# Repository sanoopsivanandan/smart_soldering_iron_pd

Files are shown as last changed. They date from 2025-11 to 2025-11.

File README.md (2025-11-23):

# Smart Soldering Iron (USB-C PD Powered)

A compact and affordable **USB-C PD powered smart soldering iron** designed for hobbyists and experimenters.
The project uses a **C210-style tip**, an **ATmega328P-AU**, and includes an **OLED display** and **accelerometer** for smart functions.

This repository currently contains **hardware-only KiCad files**. Firmware development will begin later.

---

## 📏 PCB Specifications

* **Size:** 15 mm × 107 mm
* **Layers:** 2-layer PCB
* **Form factor:** Ultra-slim to fit inside a pen-style soldering iron handle
* **Designed for:** C210-style soldering tip

---

## 🔌 Power System

* **Input:** USB-C Power Delivery
* **Supported Voltage:** Up to **12V** (currently limited to 12V for testing)
* **Purpose:** Drive the heater inside the C210 tip and power the MCU + peripherals

---

## 🧠 Microcontroller

* **MCU:** ATmega328P-AU
* **Package:** TQFP-32 (same package used in Arduino Uno SMD version)
* **Reason:** Easy programming, hobbyist-friendly, widely supported by Arduino IDE

---

## 🔥 Soldering Tip Support

* **Tip Type:** C210 series
* **Temperature Sensor:** Built-in thermocouple inside the tip
* **Connection:** Compact, high-current heater + thermocouple feedback

---

## 📟 Display & User Interface

* **Display:** 128×32 OLED
* **Navigation:** Buttons + planned touch navigation for PDF schematic viewing
* **Future UI Features:**

  * Temperature selection menu
  * Left-hand / right-hand screen rotation
  * Real-time tip temperature graph (optional)

---

## 🧭 Motion / Sleep Features

* **Accelerometer:** LIS3DHTR
* Planned features:

  * Auto-sleep when inactive
  * Wake-on-shake
  * Handle movement detection for safety

---

## 🧪 Project Status

| Category | Status |
| --- | --- |
| Hardware | ✔ Completed (prototype ready) |
| Schematics | ✔ Completed |
| PCB Layout | ✔ Completed |
| Firmware | ❌ Not started |
| Testing | ❌ Pending |

---

## 🧰 Development Plans (Firmware)

Firmware will be written primarily using **Arduino IDE**, with possible low-level C enhancements.

Planned firmware features:

* PID temperature control
* USB-C PD negotiation and power step handling
* On-screen temperature display
* Menu navigation
* Accelerometer-based sleep mode
* Tip calibration

---

## 📂 Repository Structure

* `.kicad_pro` – Main KiCad project file
* `.kicad_sch` – Schematic files
* `.kicad_pcb` – PCB layout
* `pcb_front.pdf` / `pcb_back.pdf` – PDF views of the PCB
* Additional supporting schematic sheets

Touch navigation support will be added to PDF schematics to improve readability during review.

---

## 🎯 Project Goal

To create an **affordable**, **compact**, and **easily buildable** smart soldering iron that:

* Hobbyists can assemble with basic tools
* Works reliably with USB-C PD chargers
* Uses a high-quality C210 tip
* Provides a solid foundation for firmware experimentation

---

## 📜 License

No license added yet — you may add MIT / GPL / CERN OHL based on your preference.

---

## 🤝 Contributions

Contributions and suggestions are welcome once firmware development begins!

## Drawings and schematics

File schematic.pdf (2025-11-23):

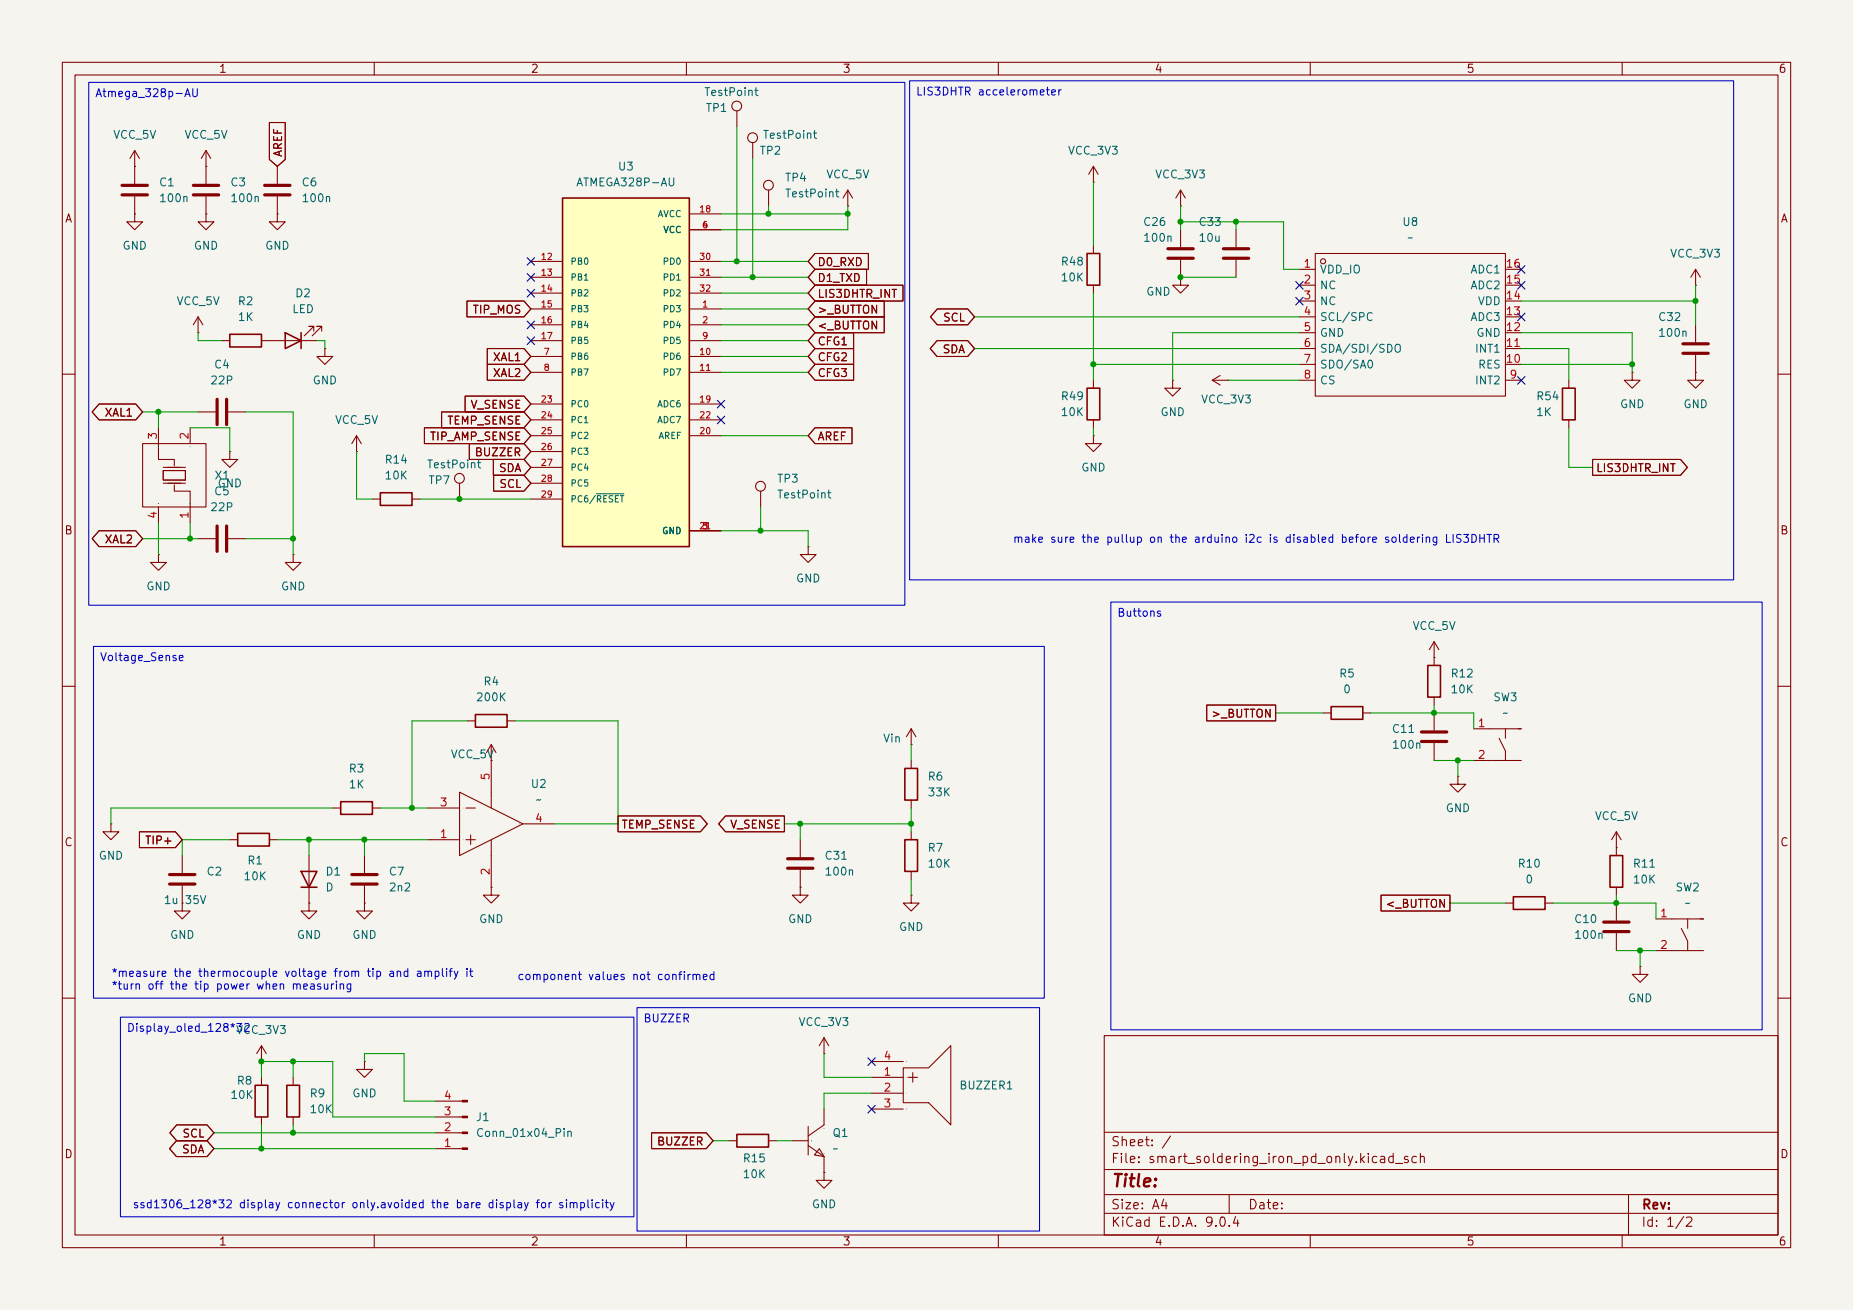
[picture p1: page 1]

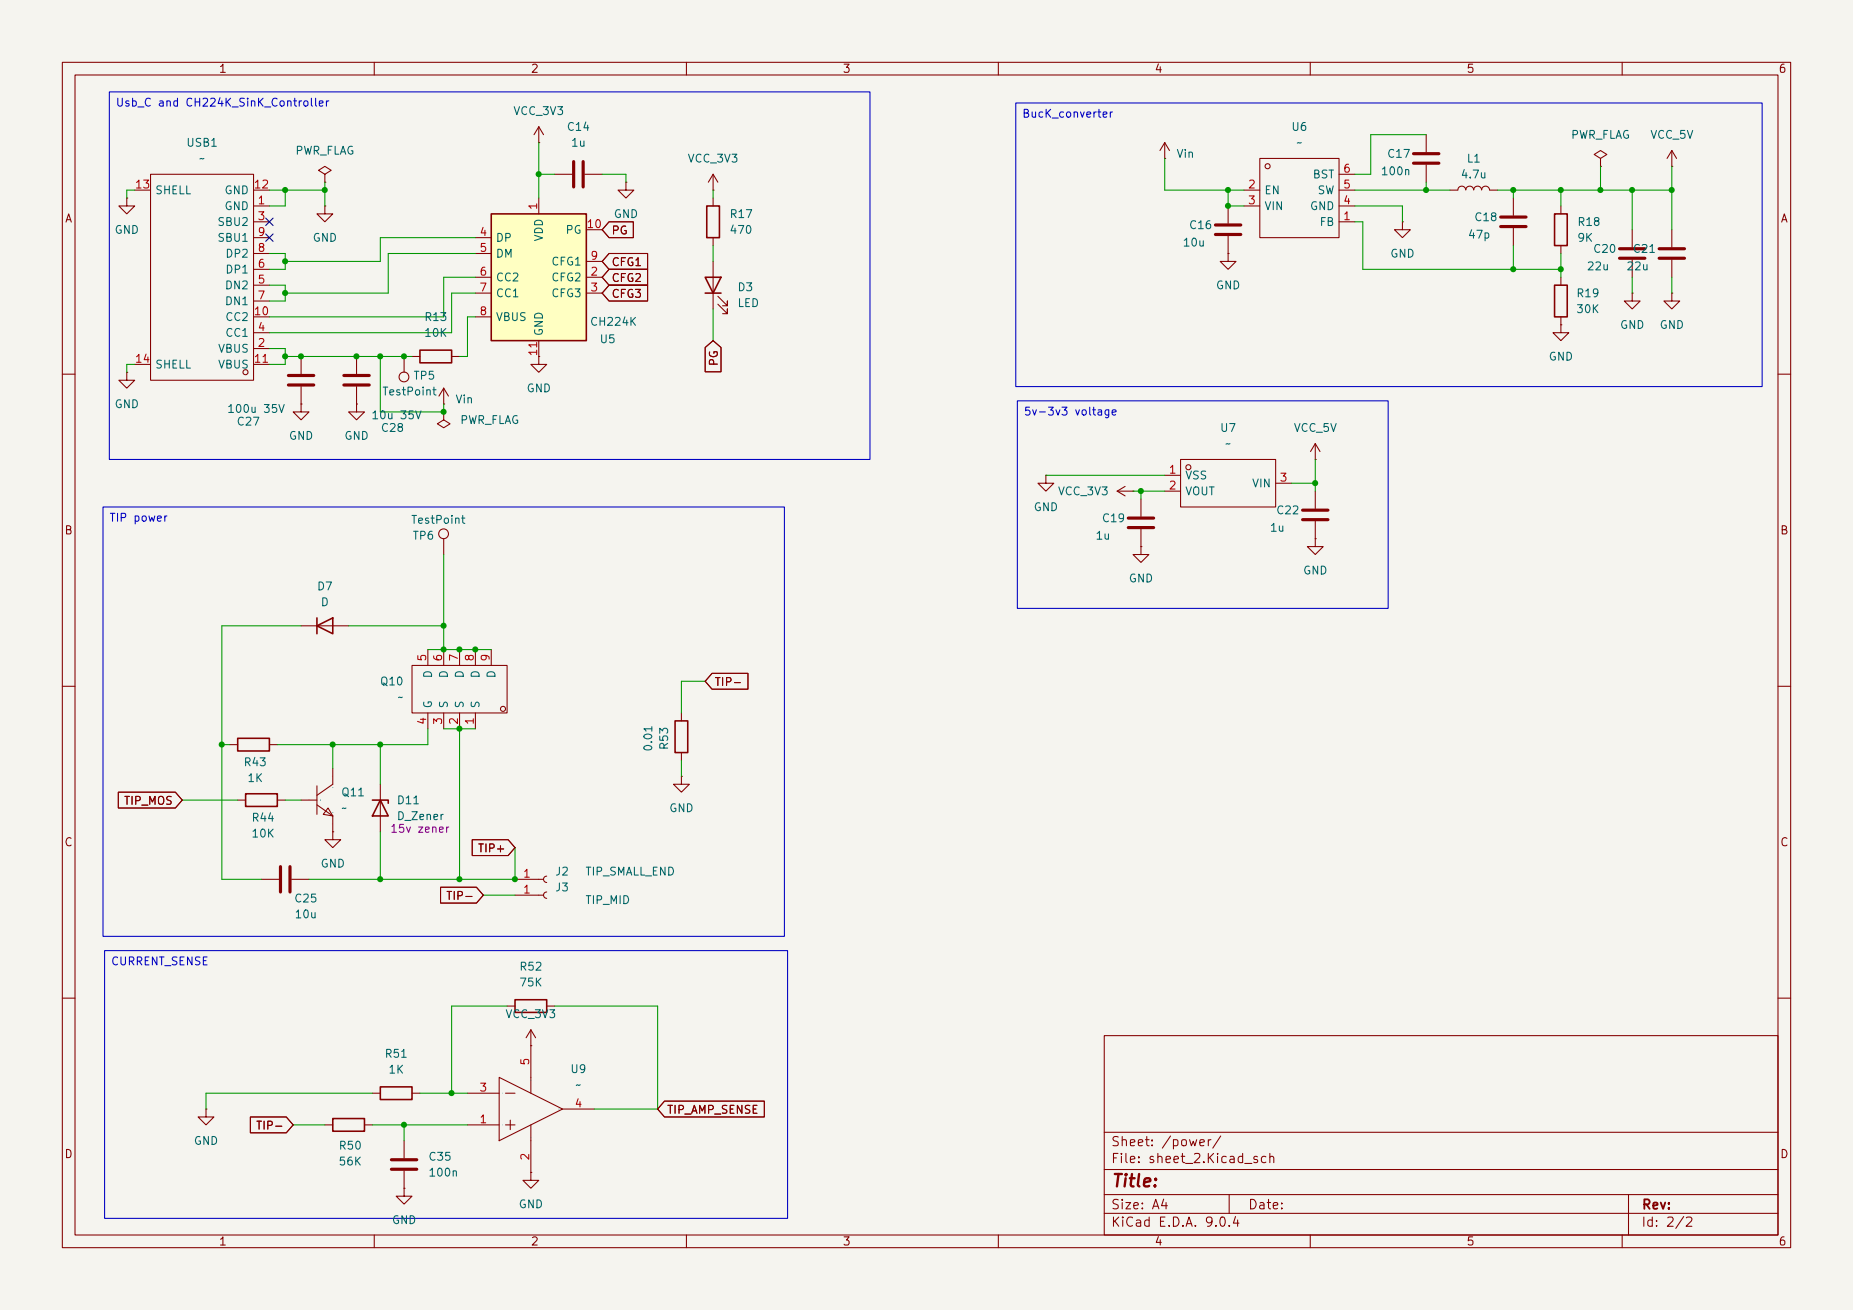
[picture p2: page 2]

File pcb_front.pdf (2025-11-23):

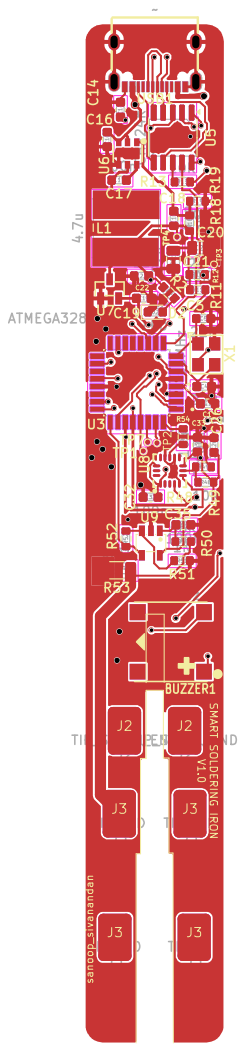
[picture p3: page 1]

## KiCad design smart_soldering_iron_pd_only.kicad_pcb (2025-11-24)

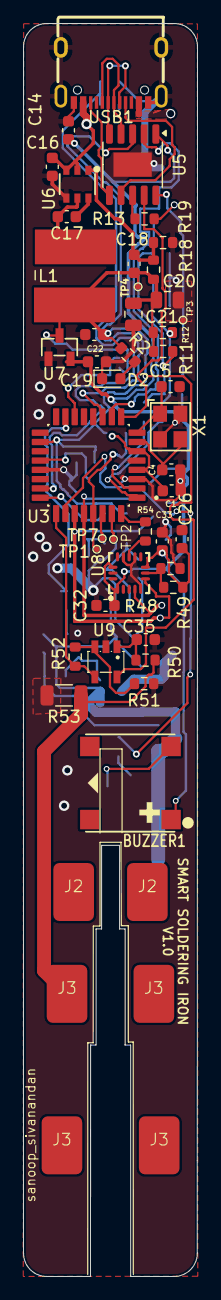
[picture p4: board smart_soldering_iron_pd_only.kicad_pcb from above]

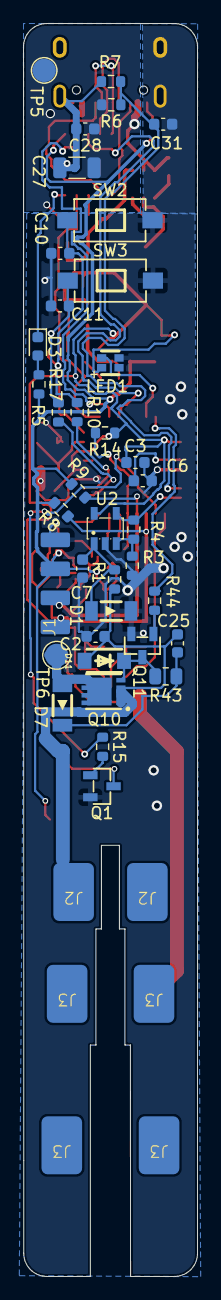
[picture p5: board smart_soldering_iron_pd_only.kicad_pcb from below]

Board: 2 copper layers, 15.0 x 107.9 mm, 94 parts (44 on the bottom side), 51 nets.

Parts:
BUZZER1: 2.7kHz; BUZZER_7525A_BUZ-SMD_4P-L7.5-W7.5-P7.59-TL
C1, C3, C6, C10, C11, C17, C26, C31, C32, C35: 100n; C_0603_1608Metric
C2: 1u 35V; C_0603_1608Metric
C4, C5: 22P; C_0603_1608Metric
C7: 2n2; C_0603_1608Metric
C14, C19, C22: 1u; C_0603_1608Metric
C16, C25, C33: 10u; C_0603_1608Metric
C18: 47p; C_0603_1608Metric
C20, C21: 22u; C_0805_2012Metric
C27: 100u 35V; C_1206_3216Metric
C28: 10u 35V; C_0603_1608Metric
D1, D7: D; LL4148 LL34 SOD80 1N4148 Hottech SMD diode
D2, D3: LED; LED_0603_1608Metric
D11: D_Zener; BZT52C5V1 W8_ZENER DIODE
J1: Conn_01x04_Pin; oled_display
J2, J2#2, J2#3, J2#4: TIP_SMALL_END; TIP_PADS
J3, J3#2, J3#3, J3#4, J3#5, J3#6, J3#7, J3#8: TIP_MID; TIP_PADS
L1: 4.7u; L_Wuerth_WE-PD2-Typ-L
LED1: LED-SMD_4P-L1.6-W1.5_XL-1615RGBC-WS2812B-S
Q1, Q11: S8050_TRANSIS_25V_0.5A_npn_SOT-23-3_L2.9-W1.3-P1.90-LS2.4-BR
Q10: AON7410_POWER_N_MOS_DFN-8_L3.0-W3.0-P0.65-BL
R1, R7, R8, R9, R11, R12, R13, R14, R15, R44, R48, R49: 10K; R_0603_1608Metric
R2, R3, R51, R54: 1K; R_0603_1608Metric
R4: 200K; R_0603_1608Metric
R5, R10: 0; R_0603_1608Metric
R6: 33K; R_0603_1608Metric
R17: 470; R_0603_1608Metric
R18: 9K; R_0603_1608Metric
R19: 30K; R_0603_1608Metric
R43: 1K; R_0805_2012Metric
R50: 56K; R_0603_1608Metric
R52: 75K; R_0603_1608Metric
R53: 0.01; R_1206_3216Metric
SW2, SW3: push_button_3.5x6x2.5Hmm SMD Rectangle Tactile micro Switch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
TP1, TP2, TP3, TP4, TP7: TestPoint; TestPoint_Pad_D1.5mm
TP5, TP6: TestPoint; TestPoint_Pad_D2.0mm
U2, U9: LM321_SOT-23-5_L3.0-W1.7-P0.95-LS2.8-BR
U3: ATMEGA328P-AU; ATMEGA328P-AU_QFP80P900X900X120-32N
U5: CH224K; SSOP-10-1EP_3.9x4.9mm_P1mm_EP2.1x3.3mm
U6: DIODES AP63300WU-7_buck_TSOT-23-6_L2.9-W1.6-P0.95-LS2.8-BR
U7: XC6206P332MR_SOT-23-3_L2.9-W1.3-P1.90-LS2.4-BR
U8: ST LIS3DHTR_ACCELEROMETER_LGA-16_L3.0-W3.0-P0.50-TL
USB1: USB-C-SMD_TYPE-C-6PIN-2MD-073
X1: 16MHz; 16_mhz_OSC-SMD_4P-L3.2-W2.5-BL

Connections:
<_BUTTON: R10.2, U3.2 (PD4)
>_BUTTON: R5.2, U3.1 (PD3)
AREF: C6.1, U3.20 (AREF)
BUZZER: R15.1, U3.26 (PC3)
CFG1: U3.9 (PD5), U5.9 (CFG1)
CFG2: U3.10 (PD6), U5.2 (CFG2)
CFG3: U3.11 (PD7), U5.3 (CFG3)
D0_RXD: TP1.1, U3.30 (PD0)
D1_TXD: TP2.1, U3.31 (PD1)
GND: C1.2, C2.2, C3.2, C4.2, C5.2, C6.2, C7.2, C10.1, C11.1, C14.2, C16.2, C19.2, C20.2, C21.2, C22.2, C26.1, C27.2, C28.2, C31.2, C32.1, C33.1, C35.2, D1.1 (K), D2.1 (K), J1.4, LED1.3 (GND), Q1.2 (E), Q11.2 (E), R3.1, R7.1, R19.2, R49.1, R51.1, R53.2, SW2.2, SW3.2, TP3.1, U2.2 (V-), U3.3 (GND), U3.5 (GND), U3.21 (GND), U5.11 (GND), U6.4 (GND), U7.1 (VSS), U8.5 (GND), U8.10 (RES), U8.12 (GND), U9.2 (V-), USB1.1 (GND), USB1.12 (GND), USB1.13 (SHELL), USB1.14 (SHELL), X1.2 (GND), X1.4 (GND)
LED_RGB: LED1.4 (DI), U3.14 (PB2)
LIS3DHTR_INT: R54.1, U3.32 (PD2)
unnamed: BUZZER1.2 (-), Q1.3 (C)
unnamed: C10.2, R10.1, R11.1, SW2.1
unnamed: C11.2, R5.1, R12.1, SW3.1
unnamed: C7.1, D1.2 (A), R1.2, U2.1 (IN+)
unnamed: D2.2 (A), R2.2
unnamed: D3.2 (A), R17.1
unnamed: D7.2 (A), Q10.5 (D), Q10.6 (D), Q10.7 (D), Q10.8 (D), Q10.9 (D), TP6.1
unnamed: C25.2, D7.1 (K), R43.1
unnamed: D11.1 (K), Q10.4 (G), Q11.3 (C), R43.2
unnamed: Q1.1 (B), R15.2
unnamed: Q11.1 (B), R44.2
unnamed: R3.2, R4.1, U2.3 (IN-)
unnamed: R14.2, TP7.1, U3.29 (PC6/~RESET)
unnamed: U5.7 (CC1), USB1.4 (CC1)
unnamed: U5.6 (CC2), USB1.10 (CC2)
unnamed: U5.5 (DM), USB1.5 (DN2), USB1.7 (DN1)
unnamed: U5.4 (DP), USB1.6 (DP1), USB1.8 (DP2)
unnamed: R13.2, U5.8 (VBUS)
unnamed: C17.1, U6.6 (BST)
unnamed: C18.2, R18.2, R19.1, U6.1 (FB)
unnamed: C17.2, L1.1, U6.5 (SW)
unnamed: R54.2, U8.11 (INT1)
unnamed: R48.1, R49.2, U8.7 (SDO/SA0)
unnamed: C35.1, R50.2, U9.1 (IN+)
unnamed: R51.2, R52.1, U9.3 (IN-)
PG: D3.1 (K), U5.10 (PG)
SCL: J1.2, R9.1, U3.28 (PC5), U8.4 (SCL/SPC)
SDA: J1.1, R8.1, U3.27 (PC4), U8.6 (SDA/SDI/SDO)
TEMP_SENSE: R4.2, U2.4 (OUT), U3.24 (PC1)
TIP+: C2.1, C25.1, D11.2 (A), J2#3.1, Q10.1 (S), Q10.2 (S), Q10.3 (S), R1.1
TIP-: J3#3.1, R50.1, R53.1
TIP_AMP_SENSE: R52.2, U3.25 (PC2), U9.4 (OUT)
TIP_MOS: R44.1, U3.15 (PB3)
VCC_3V3: BUZZER1.1 (+), C14.1, C19.1, C26.2, C32.2, C33.2, J1.3, R8.2, R9.2, R17.2, R48.2, U5.1 (VDD), U7.2 (VOUT), U8.1 (VDD_IO), U8.8 (CS), U8.14 (VDD)
VCC_5V: C1.1, C3.1, C18.1, C20.1, C21.1, C22.1, L1.2, LED1.2 (VDD), R2.1, R11.2, R12.2, R14.1, R18.1, TP4.1, U2.5 (V+), U3.4 (VCC), U3.6 (VCC), U3.18 (AVCC), U7.3 (VIN), U9.5 (V+)
V_SENSE: C31.1, R6.1, R7.2, U3.23 (PC0)
Vin: C16.1, C27.1, C28.1, R6.2, R13.1, TP5.1, U6.2 (EN), U6.3 (VIN), USB1.2 (VBUS), USB1.11 (VBUS)
XAL1: C4.1, U3.7 (PB6), X1.3 (OSC2)
XAL2: C5.1, U3.8 (PB7), X1.1 (OSC1)

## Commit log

2025-11-22 files uploaded
    [bms_with_charging.kicad_sch, sheet_2.kicad_sch, smart_soldering_iron_pd_only.kicad_pcb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]
2025-11-22 added fillet to the pcb
    [smart_soldering_iron_pd_only.kicad_pcb]
2025-11-23 added reset
    [smart_soldering_iron_pd_only.kicad_pcb, smart_soldering_iron_pd_only.kicad_sch]
2025-11-23 added name and version to the silk screen
    [smart_soldering_iron_pd_only.kicad_pcb, smart_soldering_iron_pd_only.kicad_sch]
2025-11-23 error in tip dimension,added buzzer,increased length to 11cm
    [smart_soldering_iron_pd_only.kicad_pcb, smart_soldering_iron_pd_only.kicad_sch]
2025-11-23 minor adjustment in silk screen
    [smart_soldering_iron_pd_only.kicad_pcb]
2025-11-23 Add initial README for Smart Soldering Iron project
    This README provides an overview of the Smart Soldering Iron project, including specifications, power system, microcontroller details, and future development plans.
2025-11-23 added rgb led
    [smart_soldering_iron_pd_only.kicad_pcb, smart_soldering_iron_pd_only.kicad_sch]
2025-11-24 connected 5v to the tip amp measure
    [sheet_2.kicad_sch, smart_soldering_iron_pd_only.kicad_pcb]
